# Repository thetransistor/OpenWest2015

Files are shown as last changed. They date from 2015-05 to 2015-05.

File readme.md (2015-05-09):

# OpenWest 2015 Electronic Badge
[OpenWest](https://www.openwest.org/) and [theTransistor](http://thetransistor.com/) bring you another fun conference badge.

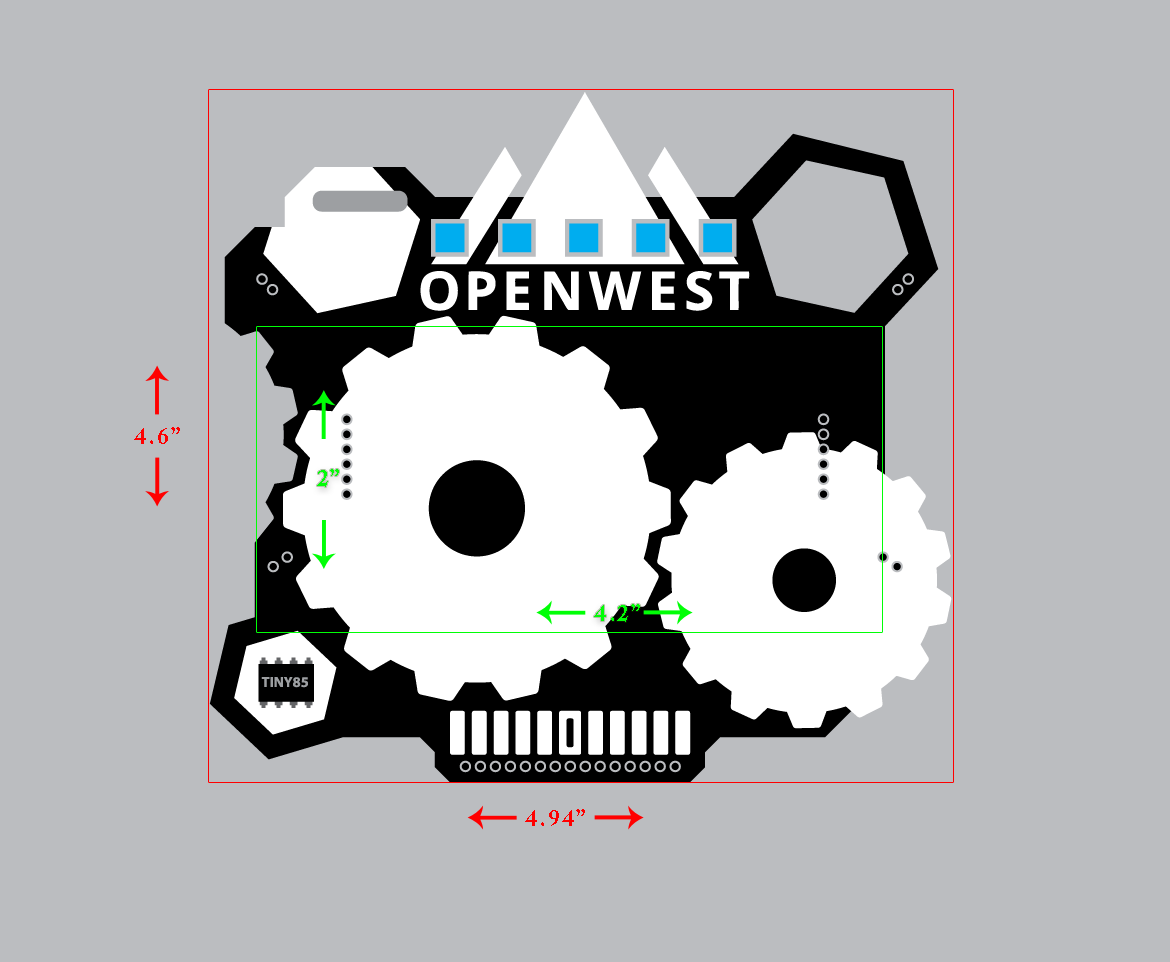
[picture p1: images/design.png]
OpenWest 2015 Badge

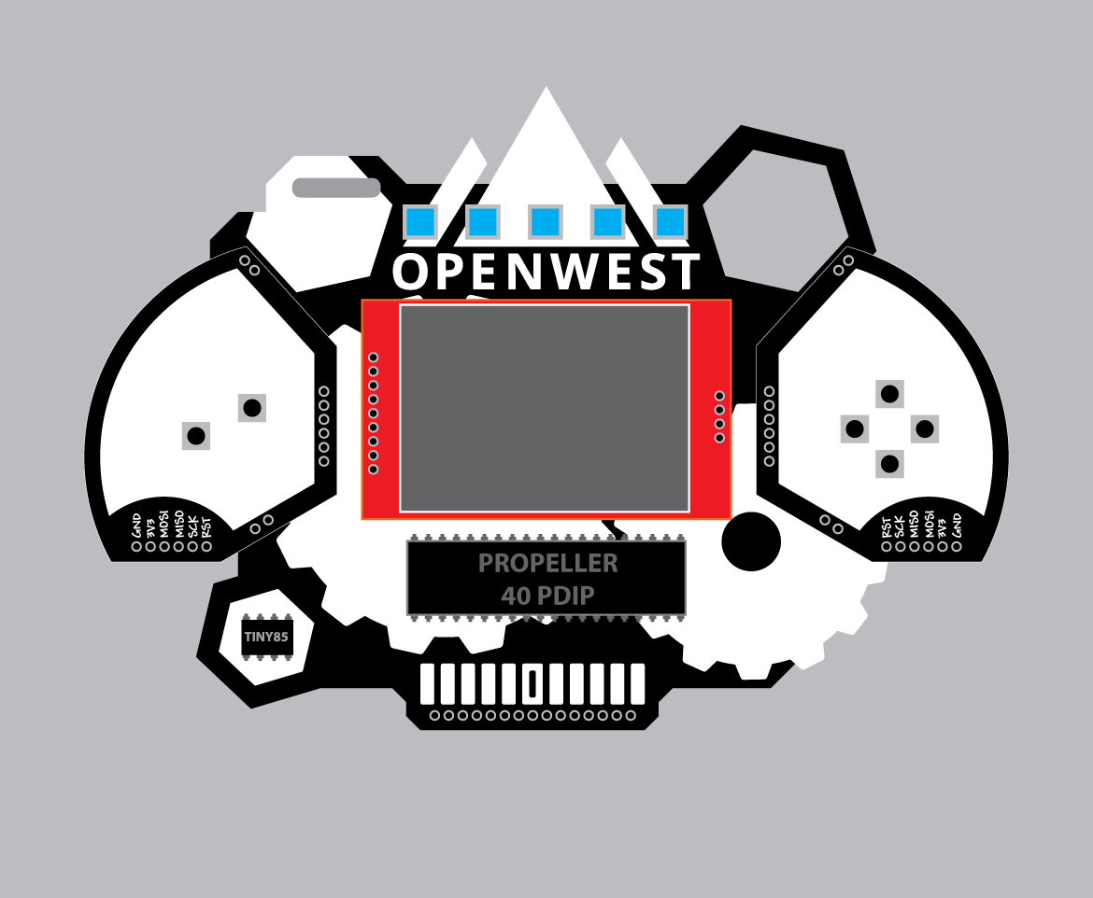
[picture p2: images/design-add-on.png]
OpenWest 2015 Add-On Kit


##Badge Parts List
- 1x Badge PCB
- 1x [ATTiny85](http://www.atmel.com/devices/attiny85.aspx)
- 1x 3xAAA Battery Holder
- 1x Push Button
- 1x Power Switch
- 5x RGB LEDs (WS2812b)
- 6x 0.1uF Capacitors, Ceramic
  
##Badge Add-On Kit Parts List
- 2x Button Board PCBs
- 1x [Parallax Propeller mCU](https://www.parallax.com/product/p8x32a-d40)
- 1x 40 Pin Socket for mCU
- 1x 2.2inch SPI TFT Display
  - [ILI9341 Controller](http://www.adafruit.com/datasheets/ILI9341.pdf)
  - 320x240 Resolution
- 1x 5mhz Crystal Oscillator (mCU runs at 80mhz) 
- 1x 24LC256 EEPROM
- 1x FTD434P MOSFET
- 1x 3.3v LDO Voltage Regulator
- 1x Tilt Switch
- 6x Push Buttons
- 1x Power Switch
- 10x 10k Resistors (labeled 103)
- 2x 10 ohm Resistors (labeled 100)
- 2x 1uF Ceramic Capacitors (with clear backing)
- 2x 0.1uF Ceramic Capacitors (with white backing)
- 1x 40 Pin Header Strip
- 1x SD to microSD Card Adapter
- 1x 128MB microSD Card

##Credits:

**Electronics Work & Processing**
- Compukidmike
- Devino

**Original Design**
- D3c4f

**QA, Assembly, & Loading**
- Animcogn
- Anthony (Demos)
- Trilog
- Nemus
- Evan (Sausage Assassin)
- Damon (Remote) 
- Compukidmike
- Yukaia
- D3c4f
- ProgrammerQ
- aarobc (l3mur)
- Tyrel
- AJ Oneal
- Jay (GraySands)

**Special Thanks**
- MindJuJu
- OpenWest Core Team
- This wonderful community!

##Questions and Comments
Questions and comments can be directed twards the following forms of communication:
- \#dc801 on freenode
- d3c4f [at] thetransistor [dot] com

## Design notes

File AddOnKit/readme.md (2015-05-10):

#How To Hack The Add On#
The add on kit is a [Propeller](http://en.wikipedia.org/wiki/Parallax_Propeller) environment with 6 buttons,
a display, and an SD card. There is an EEPROM bootloader that looks on the SD card and loads the program named run.bin.

##Using the Bitmap Loader##
The bitmap loader program is found under Software/BMP Loader.  It will cycle through two bitmaps it finds
on the SD card.  It will first load default.bmp, then 1.bmp, the back to default.bmp, then 1.bmp, etc, ad nauseum.

To run it, copy all of the contents of Software/BMP Loader to the SD card.

Some notes about creating your own bitmap:
- The badge add on kit is designed to be played while the badge is still around your neck, so when it's hanging the screen is upside down. If you want the bitmaps to be viewed right side up as you walk around, the bitmaps must be flipped both vertically and horizontally.
- The software is pretty picky about the bitmap format. I was successful with exporting the bitmap from GIMP with _**Do not write color space information**_ set and Advanced options set to _**24 bits R8 G8 B8**_

##Using the Button Test##
The button test program shows a letter on the screen for each button.  When a button is pressed the letter corresponding to the button disappears. Use the run.bin file to load the program onto your SD card and run it. Use the spin files to see and modify the source.

##Writing Your Own Code##
- Go get [Propeller IDE](http://developer.parallax.com/projects/propelleride/).
- Write a program in Spin
  - [Intro to Spin programming language](http://letsmakerobots.com/node/18214)
  - [Propeller Spin Tutorials](http://learn.parallax.com/propeller-spin-tutorials)
  - [Helpful Propeller Instructable](http://www.instructables.com/id/Programming-the-Propeller-Microcontroller/)
  - [Badge Spin Example](https://github.com/thetransistor/OpenWest2015/tree/master/AddOnKit/Software)
- Build the program in the IDE
- Rename the binary to run.bin
- Put the binary on the SD card
- Profit!!!

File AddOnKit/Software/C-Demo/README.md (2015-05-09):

C++ Demo
=============
This is a basic demo of using C++ on the OpenWest 2015 conference badge. The LCD driver was converted using spin2cpp. 

##Writing Your Own Code##
- Go get [SimpleIDE](http://learn.parallax.com/propeller-c-set-simpleide).
- Write a program in C++ or convert a library from spin
  - [Propeller GCC Tutorials](https://sites.google.com/site/propellergcc/documentation/tutorials)
  - [spin2cpp Tutorials](https://sites.google.com/site/propellergcc/documentation/tutorials/spin2cpp)
- Build the program in the IDE
- Rename the binary to run.bin
- Put the binary on the SD card
- Profit!!!

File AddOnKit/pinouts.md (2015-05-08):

# OpenWest 2015 Electronic Badge Pinout
Pinouts for the add on kit.

LCD Pin | Propeller IO
--------|--------------
CS | P7
RST | P8
D/C | P9
MOSI | P10
SC | P11
MISO | P21

Misc | Propeller IO
---|---
Backlight | P6
TILT Sensor | P16

SD Card | Propeller IO
---|---
CS | P5
MOSI | P4
MISO | P3
SCK | P21

EEPROM | Propeller IO
---|---
SCL | P28
SDA | P29

Button | Propeller IO
---|---
Up | P0
Down | P1
Left | P27
Right | P26
A | P13
B | P14

## Serial EEPROM Programming / Spin Connection
NOTE: Verify your FTDI is using 3.3v AND 3.3v logic levels!

FTDI Serial | Badge
---|---
RTS | RST
TX | RX
RX | TX
GND | GND

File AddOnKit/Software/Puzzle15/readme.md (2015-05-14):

#15 Sliding Puzzle 15 Game
Designed for the upgraded badge from the OpenWest 2015 Conference

[Author: Michael Peters](https://github.com/bluehawk)

"Totally open license, you may use this code however you wish, but I'm not responsible for your actions."

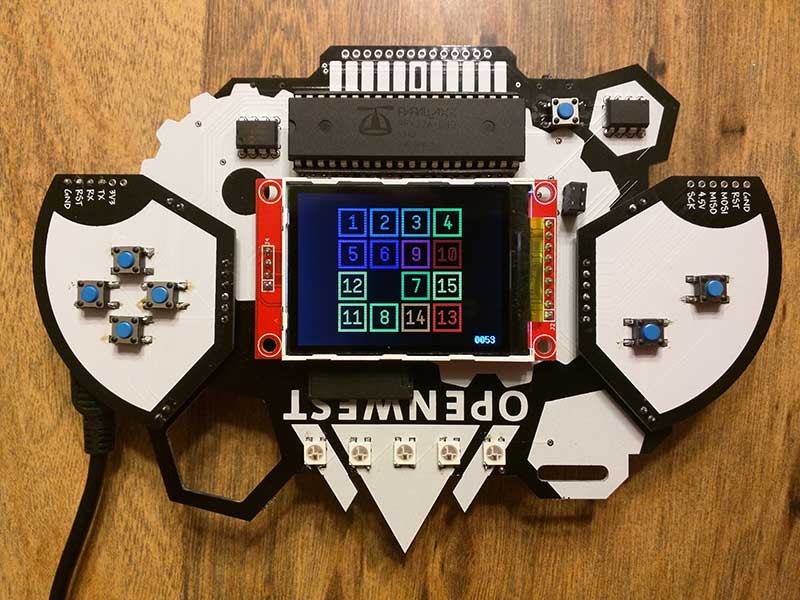
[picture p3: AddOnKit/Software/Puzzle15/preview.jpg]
Step One Image


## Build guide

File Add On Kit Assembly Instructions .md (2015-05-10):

# OpenWest 2015 Electronic Badge Add-On Kit
Assembly Instructions
(Adapted from original instructions created by Compukidmike)

## Step 1: Identify Parts
Step 1: Identify Parts
You should have the following parts in your kit:
- 2x Button Boards
- 1x [2.2" Color LCD](http://www.adafruit.com/datasheets/ILI9341.pdf)
- 1x [Propeller Microcontroller](https://www.parallax.com/product/p8x32a-d40)
- 1x 40 Pin Socket
- 6x Tactile Buttons
- 1x Slide Switch
- 1x Tilt Switch
- 2x 0.1uF Capacitors (in the white packaging)
- 2x 1uF Capacitors (in the clear packaging)
- 10x 10K Ohm Resistors
- 2x 10 Ohm Resistors
- 1x Voltage Regulator
- 1x Mosfet
- 1x 5 MHZ Crystal
- 1x EEPROM
- 1x Micro SD Card
- 1x SD Card Adapter
- 1x Pin Strip

If you are missing parts, please let us know. 
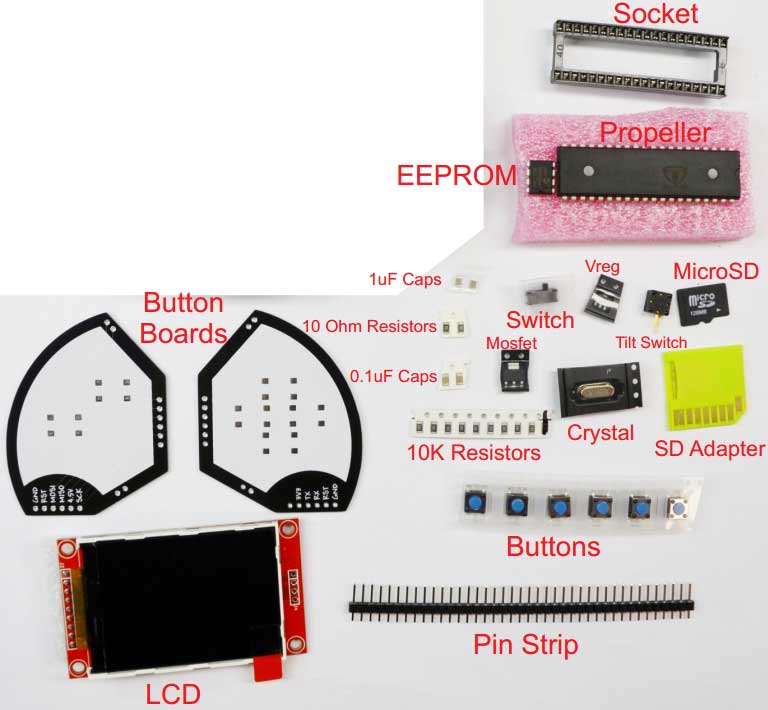
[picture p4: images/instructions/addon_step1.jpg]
Step One Image


NOTE: The surface mount parts come in a plastic or paper tray with a thin plastic film
over them. You will need to peel this plastic off to get the parts out. BE CAREFUL
when doing this as these small parts tend to go flying everywhere.

NOTE: The easiest way to solder surface mount parts is to first put solder on one of
the pads on the board. Then, while holding the soldering iron on that pad to keep the
solder melted, use the tweezers to place the part onto the board. You can then solder
the other side of the part.

## Step 2: Voltage Regulator
- Flip the board over to the back. 
- Locate the marking for VR1. This is where the Voltage Regulator goes. Be sure that the three pins on the bottom are not shorted together after soldering. This is by far the hardest part to solder on the board.

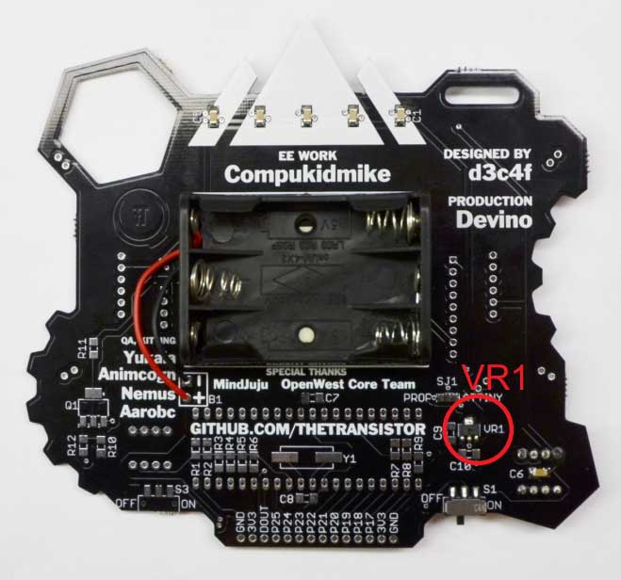
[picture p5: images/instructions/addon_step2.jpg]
Step Two Image


## Step 3: Capacitors
- There are TWO DIFFERENT types of capacitors in this kit, but they look identical. Only open one type at a time.
- The capacitors and resistors are easy to confuse because they are the same size. The resistors are black with white numbers, while the capacitors are brown and unmarked.
- First, locate the two 1uF capacitors. They are in a CLEAR plastic strip. Place them on C9 and C10 (next to the voltage regulator from the previous step).
- Next, locate the two 0.1uF capacitors. They are in a WHITE paper strip. Place them on C7 and C8 (middle of the board).

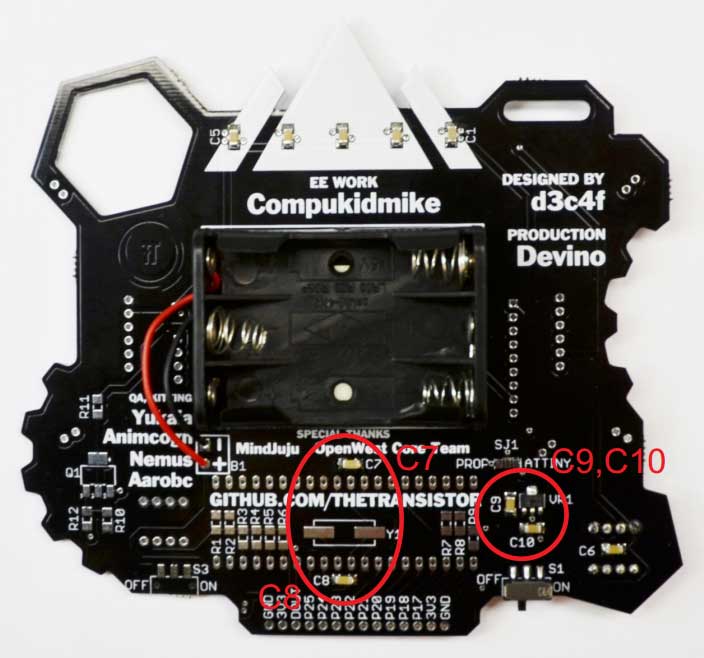
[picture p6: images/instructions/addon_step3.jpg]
Step Three Image


## Step 4: Resistors
- There are TWO DIFFERENT values of resistors.
- The strip of 10 resistors are 10K Ohms (Labeled 103 on the resistors).
- The strip of 2 resistors are 10 Ohms. (Labeled 100 on the resistors)
- Place the ten 10K resistors on R1-R10.
- Place the two 10 Ohm resistors on R11-R12.

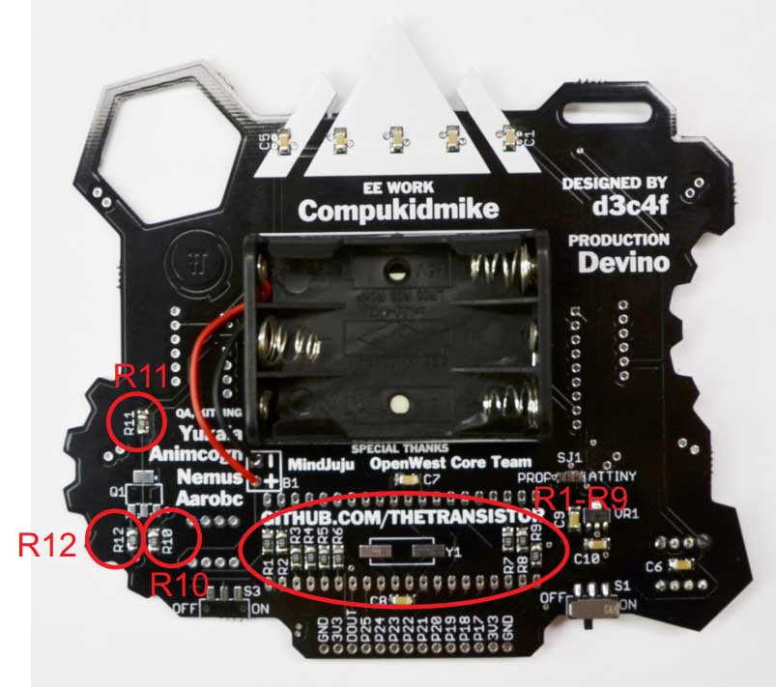
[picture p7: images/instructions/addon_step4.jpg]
Step Four Image


## Step 5: Mosfet, Crystal and Switch
- Locate Q1 and place the mosfet there.
- The Crystal goes on Y1.
- Then solder the slide switch on S3.

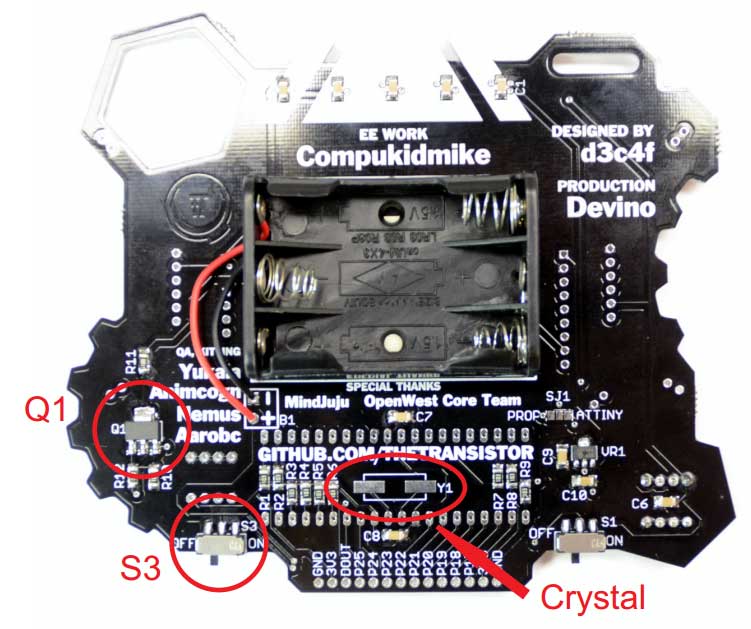
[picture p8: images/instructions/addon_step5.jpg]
Step Five Image


## Step 6: Tilt Switch, EEPROM and Socket
- Place the tilt switch on the front of the board. There are four small marks that show the outline of the switch. Make sure it lines up with the marks, and then solder the switch.
- Next, place the EEPROM. The orientation on this chip is opposite from the ATTiny85 microcontroller from the base kit. The pin 1 marking goes on the top right corner. This chip also has a half-circle shaped dimple on one side of the chip. This should face towards the right side of the board.
- Then place the 40 pin socket on the front of the board. There is a dimple on one side of the socket. Align this with the mark on the board (it should face towards the right side of the board).

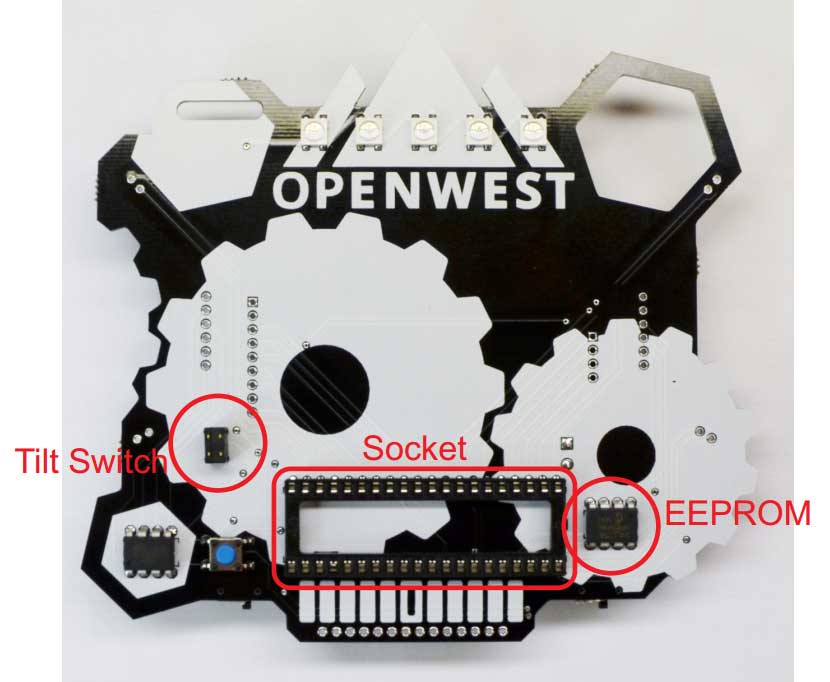
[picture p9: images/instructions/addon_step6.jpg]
Step Six Image


## Step 7: LCD
- The LCD is tricky. The first thing to note is that the display only has pins on one side. You will need to cut 4 of the pins from the pin strip to put on the display. DON’T solder them to the display yet!
- While holding the pins in place on the display, put the display in place on the front of the board.
- Carefully flip the board over and solder the first pin on the right side of the board (the pad on the board is square shaped).
- Now you need to check that the display is parallel to the front of the board. It tends to not lay flat due to the SD card socket on the back. One way to fix it is to gently squeeze the board and display where the SD card is located, while at the same time re-heating the solder joint on the first pin. When the solder melts, the screen will ‘snap’ into the correct position.
- You can then solder the rest of the pins.

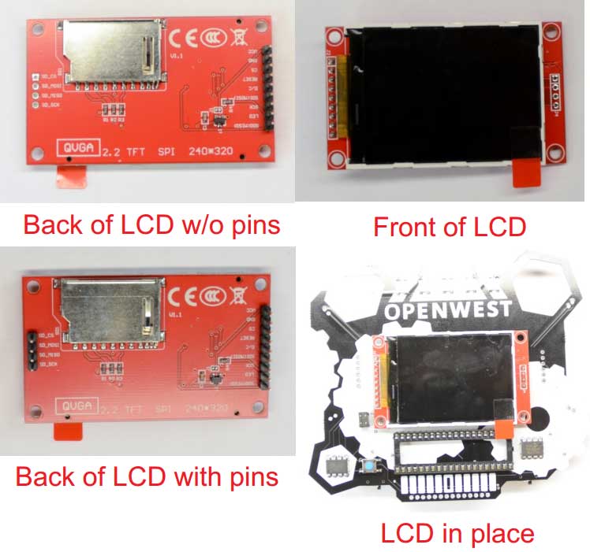
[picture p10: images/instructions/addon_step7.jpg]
Step Seven Image


##Step 8: Button Boards
- The button boards are interesting. They are both identical, but each side is
different. We will use one of each side to produce the required button layout.
- Start by soldering the Left and Right buttons on the Right board.
- Then do the top and bottom buttons
- And finally solder the two buttons on the left board.

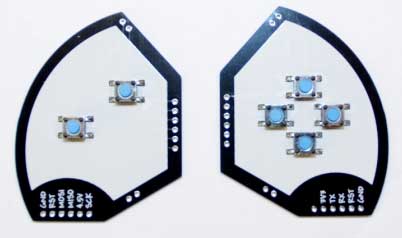
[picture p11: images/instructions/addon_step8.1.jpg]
Step Eight One Image


- Once the boards are done, you will need to cut more pins from the pin strip.
- Cut four sets of 2 pins and two sets of 6 pins.
- Place them in the main board with the long side down.
- Now place the button boards on top of the pins. They will not stay by themselves. While holding both boards, flip them over. Now gravity will help the button boards stay flat while you solder all the pins.
- Next, flip the board back over and solder the top of the pins on the button
boards.

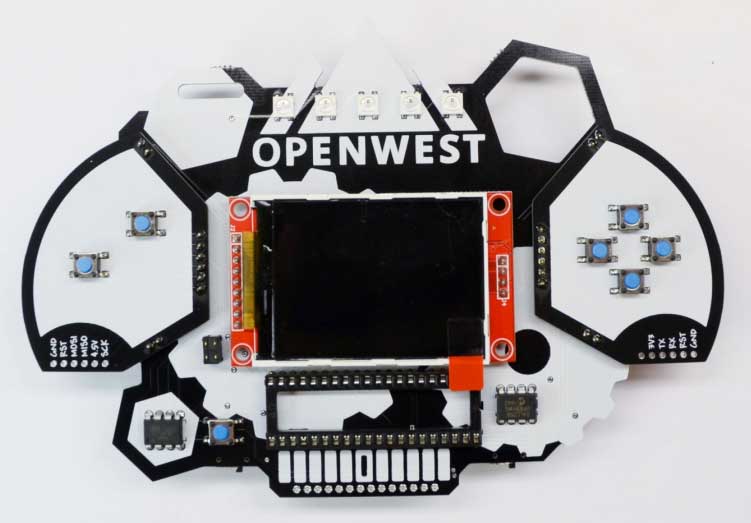
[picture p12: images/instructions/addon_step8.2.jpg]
Step Eight Two Image


## Step 9: Propeller and SD Card
- The end is near! It’s now time to put in the propeller chip. This is a big chip, and it’s expensive so please be careful with it.
- To get the chip into the socket, you will need to bend the legs inward slightly. The easiest way to do this is to put the chip on its side on a flat surface. Then GENTLY press the chip down so that all the pins on that side bend inward a little. Flip the chip over and repeat on the other side.
- Now the pins should be pointing straight down on the sides of the chip.
- Make sure that the dimple is on the right side of the chip and place it into the socket. It will take some force to press it in, so be sure that it is lined up properly.
- After the propeller is in place, put the MicroSD card into the SD adapter and place it in the top of the LCD.

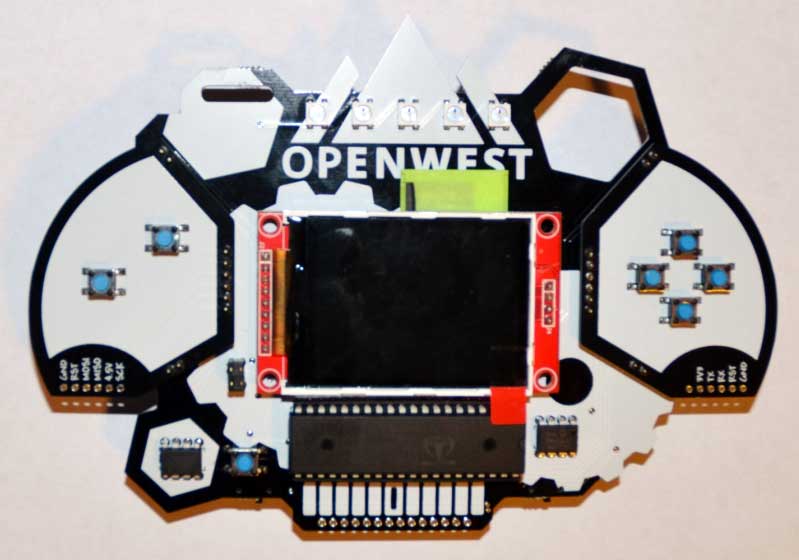
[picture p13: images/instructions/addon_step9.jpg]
Step Nine Image


## Step 9: Test
- You’re done! Put some batteries in, flip the new switch to “ON” and the LCD should light up and display some test patterns. 
- If it doesn’t, please let us know and we’d be happy to help you get it working.
- Enjoy your add-on kit!

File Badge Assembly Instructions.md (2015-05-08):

# OpenWest 2015 Electronic Badge
Assembly Instructions
(Adapted from original instructions created by Compukidmike)

## Step 1: Identify Parts
- 1x Badge PCB
- 1x [ATTiny85](http://www.atmel.com/devices/attiny85.aspx)
- 1x 3xAAA Battery Holder
- 1x Push Button
- 1x Power Switch
- 5x RGB LEDs (WS2812b)
- 6x 0.1uF Capacitors, Ceramic
- 1x Double-Sided Sticky Square

If you are missing parts, please let us know. 
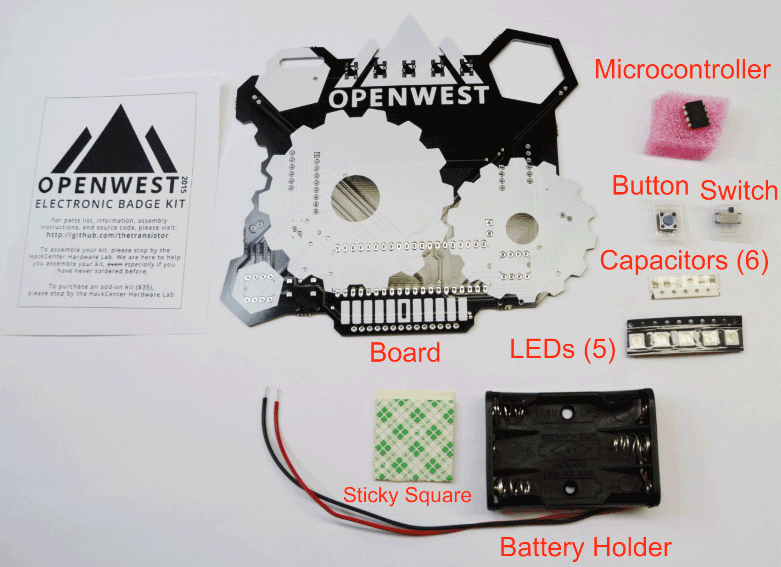
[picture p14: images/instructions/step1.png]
Step One Image


## Step 2: Capacitors and Switch
- Flip the board over to the back. Locate the markings for C1-C5 and C6.
- Solder the 6 capacitors. Orientation does not matter for the capacitors.
- Locate S1 and solder the switch there. The switch has little plastic tabs on the bottom that fit into holes on the board.
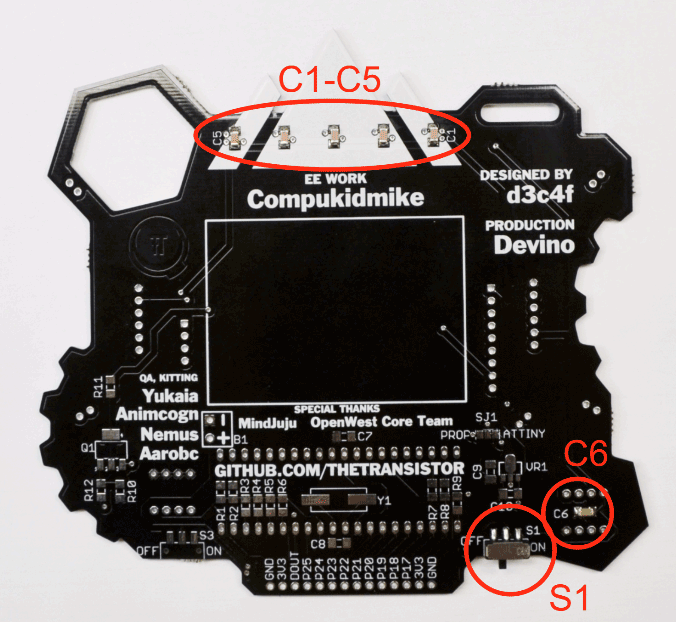
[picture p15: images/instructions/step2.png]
Step Two Image


Note: The surface mount parts come in a plastic or paper tray with a thin plastic film
over them. You will need to peel this plastic off to get the parts out. BE CAREFUL
when doing this as these small parts tend to go flying everywhere.

Note: The easiest way to solder surface mount parts is to first put solder on one of
the pads on the board. Then, while holding the soldering iron on that pad to keep the
solder melted, use the tweezers to place the part onto the board. You can then solder
the other side of the part.

## Step 3: LEDs and Button
- Flip the board back over to the front. Locate the 5 sets of pads at the top of the board, above the OPENWEST text. This is where the LEDs go.
- Orientation is critical for these parts! There are two ways to make sure you put them on the correct way. The easiest is to find the small brown rectangle inside the LED. This should be towards the top of the board. The other way is to find the cut off corner on the LED. This should correspond to a triangle on the board.
- Once you have determined the correct orientation for the LEDs, solder all 5 of them.
- Then, locate the button in the bottom left corner of the board and solder it.
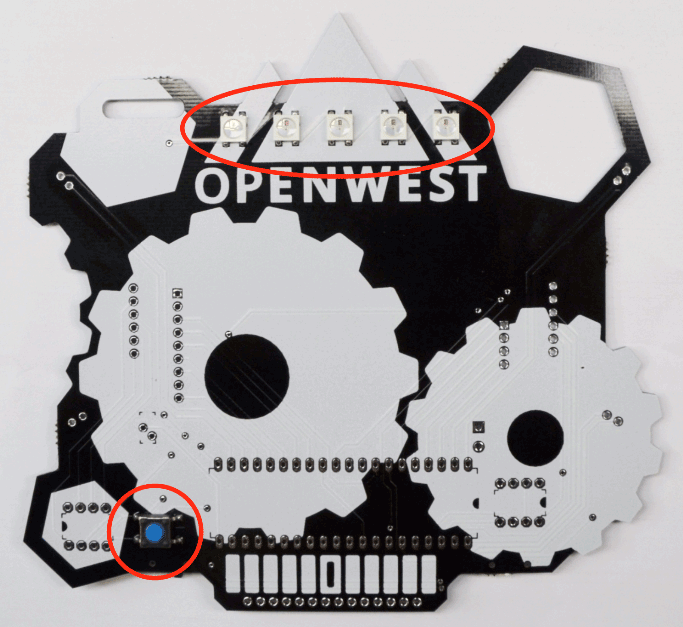
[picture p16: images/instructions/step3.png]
Step Three Image

Note: Solder the LEDs and button the same way as the capacitors. Put
solder on one pad, place the part, and then solder the rest of the pads.

## Step 4: Microcontroller
It’s time for the Microcontroller. The Badge uses an Atmel ATTiny85. Once again, orientation matters! The microcontroller goes in the bottom left corner of the board. There is a marking on the top next to pin 1. This marking should be in the bottom-left corner of the chip (pointing to the left). If you are unsure of the correct orientation, please ask us before soldering it!
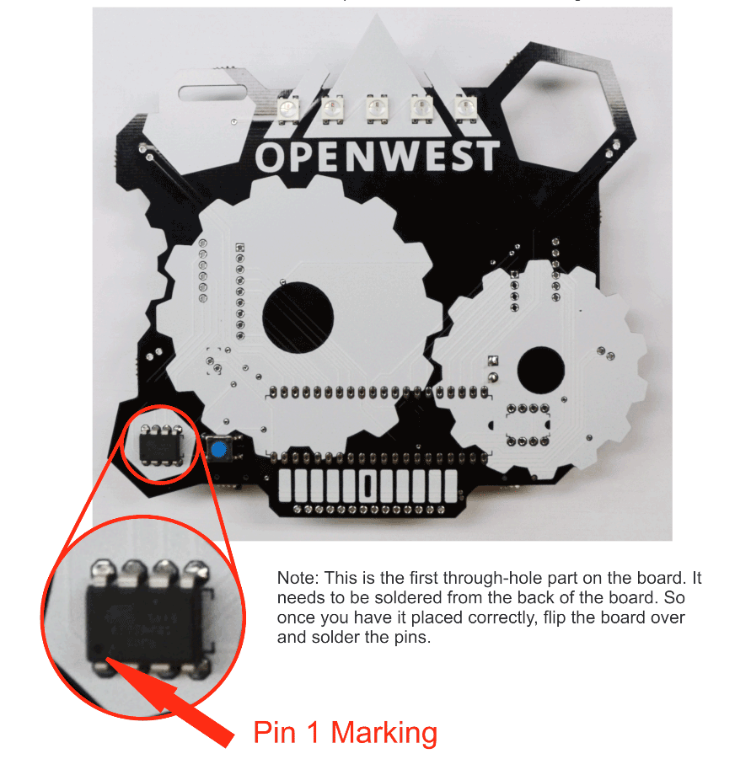
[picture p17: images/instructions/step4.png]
Step Four Image


## Step 5: Battery Holder
This is it, the final piece! 
- The first thing to do is put the sticky square on the bottom of the battery holder. You might need to adjust the wire on the bottom so that it fits in the groove.
- Then place the battery holder on the board with the wires coming out to the left.
- Now you will need to cut the wires to the correct length. They need to reach the square marked B1. The black wire goes to the “-” and the red wire goes to the “+”.
- Once you cut the wires, strip off about 1/4” of insulation.
- Place the wires through the holes and solder them on the front side of the board, then cut off the excess wire close to the board.

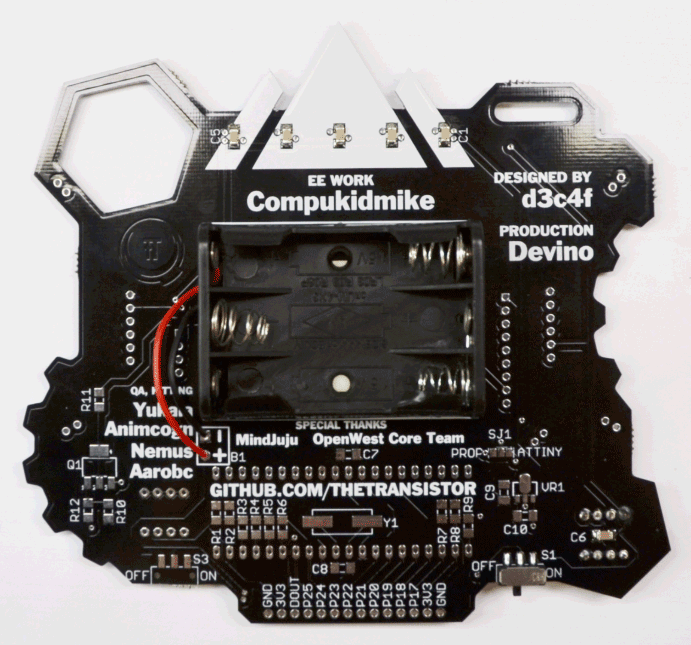
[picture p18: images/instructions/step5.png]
Step Five Image


## Step 6: Test
- Install a set of batteries (available up front)
- Slide your power switch to "ON" 
- Check that all 5 LEDs light up
- If you have any trouble, please switch off the device and bring it to one of the staff members to help you diagnose.

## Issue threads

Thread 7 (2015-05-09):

USB debugging/loading?

therebelrobot, 2015-05-09:
So I'm finding that I need to pull out the sd card and reload it every time I want to test something new on the board, which can get tedious after enough updates. Is the board expandable enough to include a usb extension? I would love to just plug this in and test out stuff without leaving my keyboard.

therebelrobot, 2015-05-09:
@d3c4f, are you the one to ask about this? I forget if it was you or someone else that built the board...

bluehawk, 2015-05-09:
From what I can tell, you could buy this (rather expensive) $15 [USB plug](https://www.parallax.com/product/32201) and connect it to the right wing of the badge to the TX, RX, RST, GND pins.

But at $15 just for a usb plug, I might just pay a bit more and get a propeller board with more expansion capability to play with.

* The $25 [USB project board](https://www.parallax.com/product/32810) has usb and lots of places to solder (permanent) connections.
* The $35 [quickstart board](https://www.parallax.com/product/40000) has a usb port, plus 8 leds and buttons on the board ready to use, plus headers that you can use to test things and reuse.
* You can get even more expensive $50 or $120 boards that include breadboards if you want to have ultimate reusability, plus things like VGA, audio, microsd, etc.

At the same time, I do like the form factor of the badge. It's a tough choice.

d3c4f, 2015-05-10:
Any 3.3v FTDI (or knockoff) programmer is capable of programming the badge. They are very handy to have separately, not just for this project but also for many other mCU work. If $15 is a bit pricey (you're just going to be playing with this from time to time), I would look into a knockoff USB -> Serial FTDI-Style device. You can get these for as little as $3 (shipped) on aliexpress.

d3c4f, 2015-05-10:
To close this out:
- You absolutely can test code over the serial connection (for USB, use an FTDI $3 for a knock off, or $15 for "the real deal") without booting to the EEPROM->SD card each from.
- With the Propeller IDE you can load code directly into RAM instead of writing to persistent storage (EEPROM / SD Card), which is SUPER handy for testing code.
- I designed the board (Picked out the major components, came up with the concept, did the artwork / outlines / etc). Compukidmike took that and did all the PCB and EE work (routing traces, checking datasheets / etc).

therebelrobot, 2015-05-11:
@bluehawk & @d3c4f, thanks a million! I'll look up getting an FTDI, and see how that goes. Super awesome concept and execution, I might add, thanks so much for an awesome OpenWest badge!

Closed 2015-05-10.

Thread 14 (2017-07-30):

2015 Add-on kit troubleshooting

dstockto, 2017-07-30:
Hey, I know this is a long shot since it has been two years, but I just got the equipment and time together today and assembled and attached the addon for my 2015 OpenWest badge. And it worked, first time. Then I loaded the BMP viewer and it worked. So then I made some images to show and they didn't work and then I found I had exported them as 32 bit instead of 24, so I fixed that and that worked. And then I turned it off and back on again and it worked. Then I turned it off and back on again and showed my wife and it worked. And then I went to show my kids and after turning it off, it wouldn't turn on again.

The original circuit with the blinkenlights is still working, it's just the add-on one. I'm pretty new to all this stuff so if you're able and willing to, if you could point me to some things to try or look at to figure out what's going on, I'd appreciate it. If not, no worries.

Thank you in advance.

d3c4f, 2017-08-02:
David,

Thanks for the questions, and sorry for the delay in answering them. I have
been at conferences for the past 2-3 weeks.

There are a couple things to check:
1) The SD data is corrupted. Try reformatting it and loading the code onto
it again.
2) The SD card is not corrupted. Try a new SD card.
3) The bootloader could be corrupted (I can't remember if it is built into
the chip or not). If it is, you will need to load a new one via the serial
programming headers for the propeller (you will likely need an FTDI
USB->Serial adapter). See link below and expand the downloads section.
4) The Propeller chip has somehow been damaged. You will need to replace
it. (see link below)

Propeller Chip:
https://www.parallax.com/product/p8x32a-d40

3.3v FTDI Programmer:
https://www.sparkfun.com/products/9873

3.3v FTDI Programmer (cheap Chinese knockoff, verify voltage!):
https://www.aliexpress.com/item/Free-shipping-1pcs-FT232RL-FTDI-USB-3-3V-5-5V-to-TTL-Serial-Adapter-Module-for/32294938771.html

I hope that helps,
d3c4f

On Sat, Jul 29, 2017 at 9:45 PM, David Stockton <notifications@github.com>
wrote:

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

dstockto, 2017-08-03:
No worries on the delay. Thank you for the reply.

I don't *think* the SD card is corrupted as I'm able to copy new things to it without error, but I'll give that a shot, or try another. I would suspect I may be dealing with suggestion 3, but I'll try the first 2 first. Hopefully, the chip isn't damaged.

Thank you for the suggestions. I'll reply back after I've tried some stuff or succeeded.

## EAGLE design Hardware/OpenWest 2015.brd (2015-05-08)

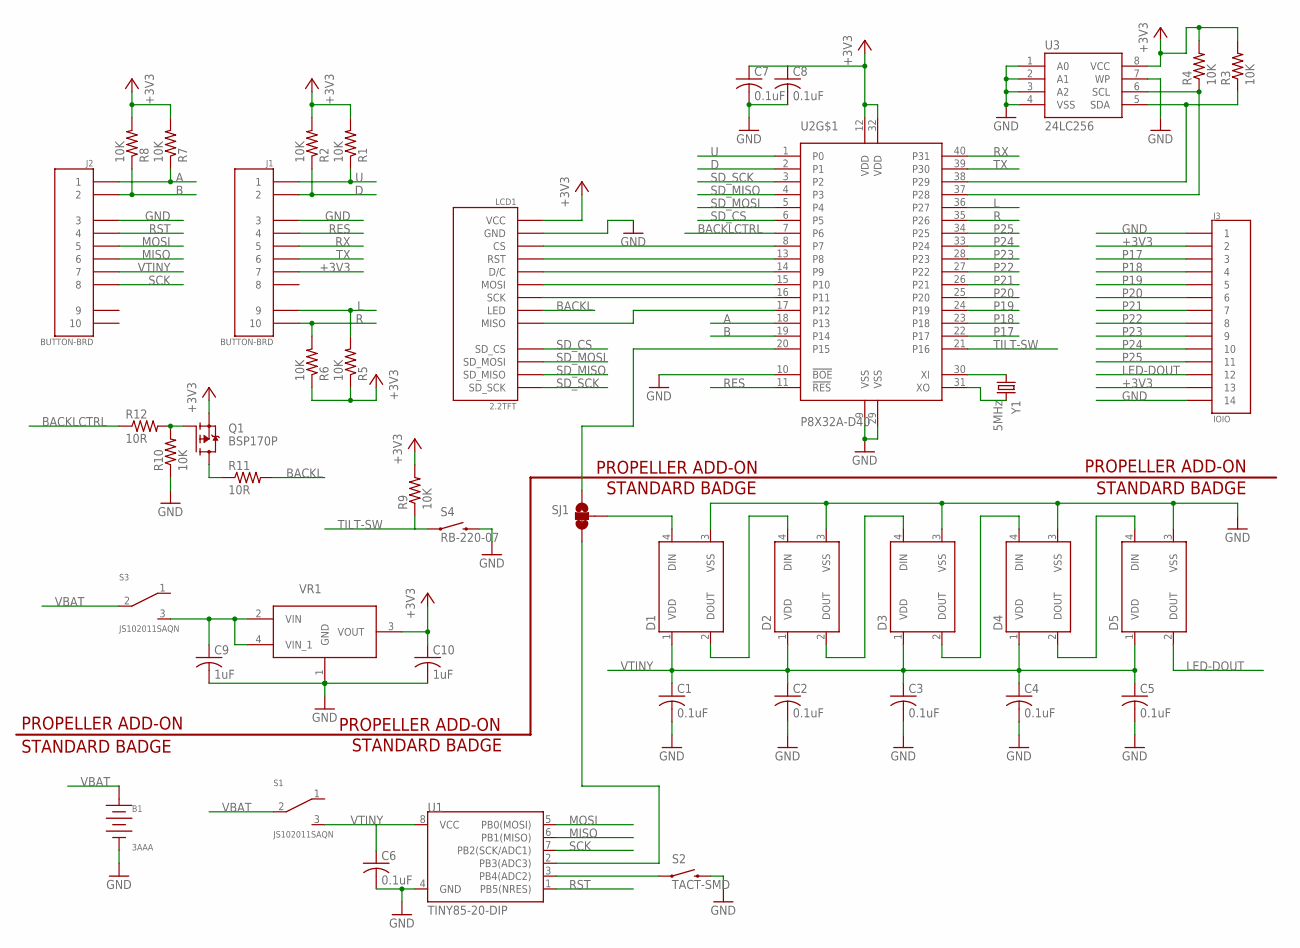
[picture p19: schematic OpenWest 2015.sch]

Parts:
B1: 3AAA; FLYING-LEADS
C1, C2, C3, C4, C5, C6, C7, C8: 0.1uF; C1206K
C9, C10: 1uF; C1206K
D1, D2, D3, D4, D5: WS2812B
J1, J2: BUTTON-BRD
J3: IOIO
LCD1: 2.2TFT
Q1: BSP170P; SOT223
R1, R2, R3, R4, R5, R6, R7, R8, R9, R10: 10K; R1206
R11, R12: 10R; R1206
S1, S3: JS102011SAQN; SAQN
S2: TACT-SMD
S4: RB-220-07; SPST
SJ1: JUMPER-PAD-3-2OF3_NC_BY_TRACE_LARGE; PAD-JUMPER-3-2OF3_NC_BY_TRACE_YES_SILK_LARGE
U1: TINY85-20-DIP; DIP08
U2: P8X32A-D40; DIP-40
U3: 24LC256; DIP08
VR1: MCP17-MCP1700T-3302E/MB; SOT150P400X160-4N
Y1: 5MHz; CRYSTAL-SMD

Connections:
+3V3: C7.1, C8.1, C10.1, J1.7, J3.P$2 (2), J3.P$13 (13), LCD1.VCC, Q1.3 (S), R1.2, R2.2, R3.2, R4.2, R5.1, R6.1, R7.2, R8.2, R9.2, U2.12 (VDD), U2.32 (VDD), U3.8 (VCC), VR1.3 (VOUT)
A: J2.1, R7.1, U2.18 (P13)
B: J2.2, R8.1, U2.19 (P14)
BACKL: LCD1.LED, R11.2
BACKLCTRL: R12.1, U2.7 (P6)
D: J1.2, R2.1, U2.2 (P1)
GND: B1.-, C1.2, C2.2, C3.2, C4.2, C5.2, C6.2, C7.2, C8.2, C9.2, C10.2, D1.3 (VSS), D2.3 (VSS), D3.3 (VSS), D4.3 (VSS), D5.3 (VSS), J1.3, J2.3, J3.P$1 (1), J3.P$14 (14), LCD1.GND, R10.1, S2.P$3 (2), S4.2, U1.4 (GND), U2.9 (VSS), U2.10 (!BOE), U2.29 (VSS), U3.1 (A0), U3.2 (A1), U3.3 (A2), U3.4 (VSS), U3.7 (WP), VR1.1 (GND)
L: J1.9, R5.2, U2.36 (P27)
LED-DOUT: D5.2 (DOUT), J3.P$12 (12)
MISO: J2.6, U1.6 (PB1(MISO))
MOSI: J2.5, U1.5 (PB0(MOSI))
unnamed: D1.4 (DIN), SJ1.2
unnamed: D1.2 (DOUT), D2.4 (DIN)
unnamed: D2.2 (DOUT), D3.4 (DIN)
unnamed: D3.2 (DOUT), D4.4 (DIN)
unnamed: D4.2 (DOUT), D5.4 (DIN)
unnamed: R4.1, U2.37 (P28), U3.6 (SCL)
unnamed: R3.1, U2.38 (P29), U3.5 (SDA)
unnamed: SJ1.3, U1.2 (PB3(ADC3))
unnamed: SJ1.1, U2.20 (P15)
unnamed: LCD1.CS, U2.8 (P7)
unnamed: LCD1.RST, U2.13 (P8)
unnamed: LCD1.D/C, U2.14 (P9)
unnamed: LCD1.MOSI, U2.15 (P10)
unnamed: LCD1.SCK, U2.16 (P11)
unnamed: LCD1.MISO, U2.17 (P12)
unnamed: U2.30 (XI), Y1.P$1 (1)
unnamed: U2.31 (XO), Y1.P$2 (2)
unnamed: C9.1, S3.3, VR1.2 (VIN), VR1.4 (VIN_1)
unnamed: S2.P$1 (1), U1.3 (PB4(ADC2))
unnamed: Q1.2 (D), Q1.4 (D), R11.1
unnamed: Q1.1 (G), R10.2, R12.2
P17: J3.P$3 (3), U2.22 (P17)
P18: J3.P$4 (4), U2.23 (P18)
P19: J3.P$5 (5), U2.24 (P19)
P20: J3.P$6 (6), U2.25 (P20)
P21: J3.P$7 (7), U2.26 (P21)
P22: J3.P$8 (8), U2.27 (P22)
P23: J3.P$9 (9), U2.28 (P23)
P24: J3.P$10 (10), U2.33 (P24)
P25: J3.P$11 (11), U2.34 (P25)
R: J1.10, R6.2, U2.35 (P26)
RES: J1.4, U2.11 (!RES)
RST: J2.4, U1.1 (PB5(NRES))
RX: J1.5, U2.40 (P31)
SCK: J2.8, U1.7 (PB2(SCK/ADC1))
SD_CS: LCD1.SD_CS, U2.6 (P5)
SD_MISO: LCD1.SD_MISO, U2.4 (P3)
SD_MOSI: LCD1.SD_MOSI, U2.5 (P4)
SD_SCK: LCD1.SD_SCK, U2.3 (P2)
TILT-SW: R9.1, S4.1, U2.21 (P16)
TX: J1.6, U2.39 (P30)
U: J1.1, R1.1, U2.1 (P0)
VBAT: B1.+, S1.2, S3.2
VTINY: C1.1, C2.1, C3.1, C4.1, C5.1, C6.1, D1.1 (VDD), D2.1 (VDD), D3.1 (VDD), D4.1 (VDD), D5.1 (VDD), J2.7, S1.3, U1.8 (VCC)

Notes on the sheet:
STANDARD BADGE
PROPELLER ADD-ON

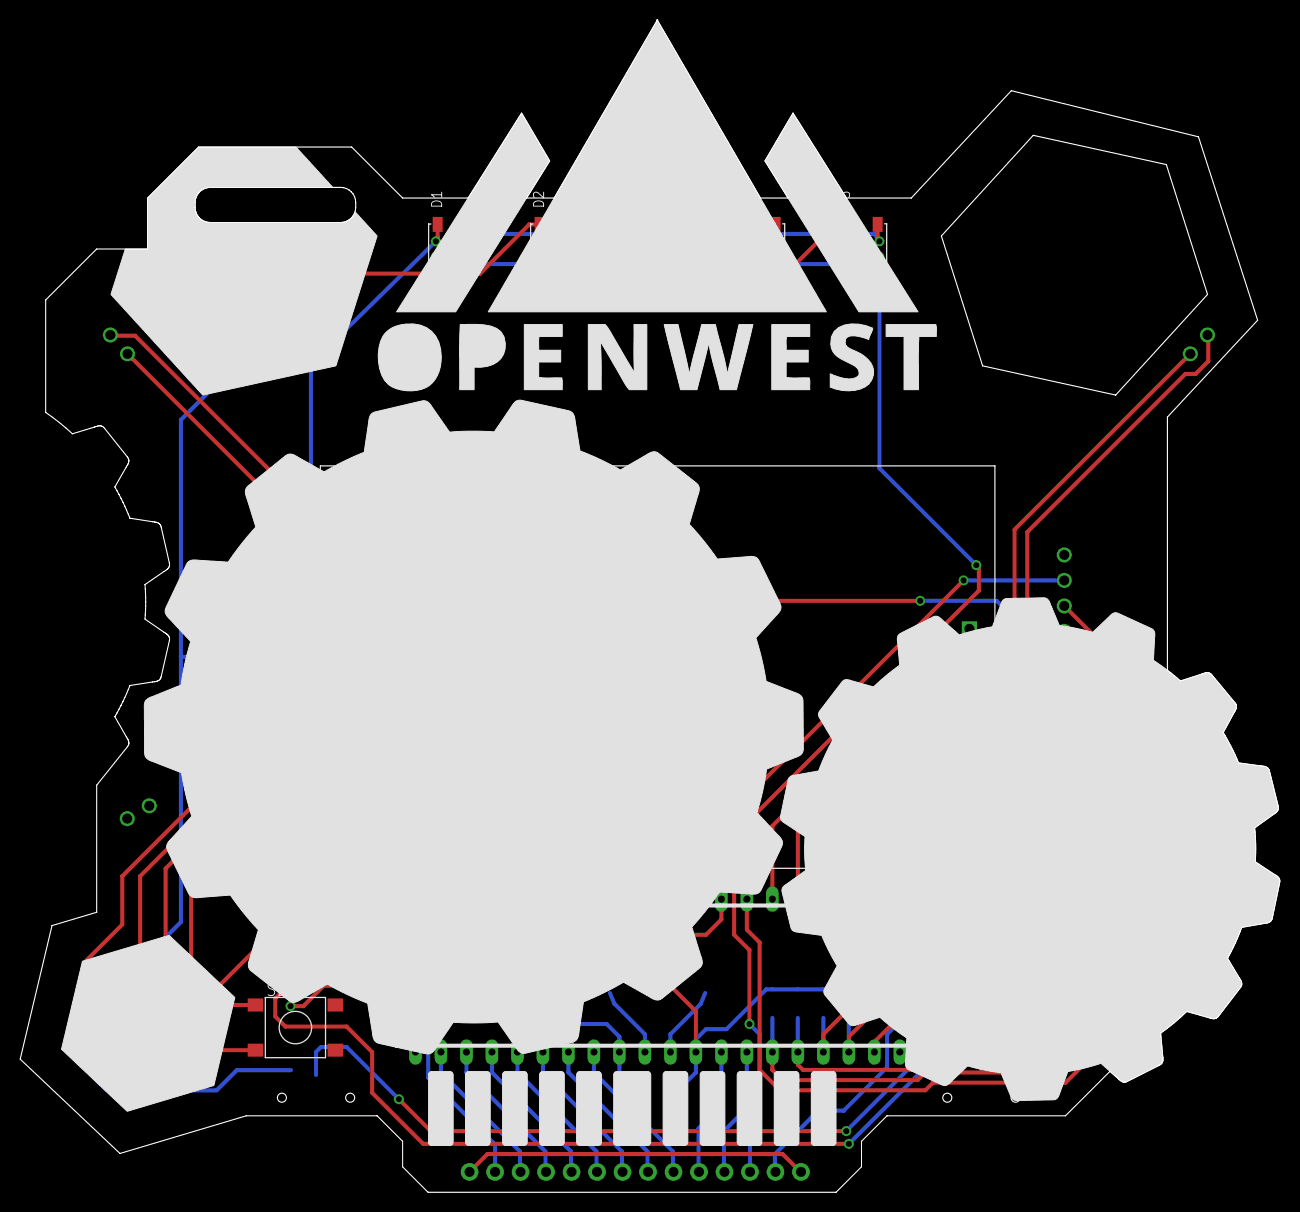
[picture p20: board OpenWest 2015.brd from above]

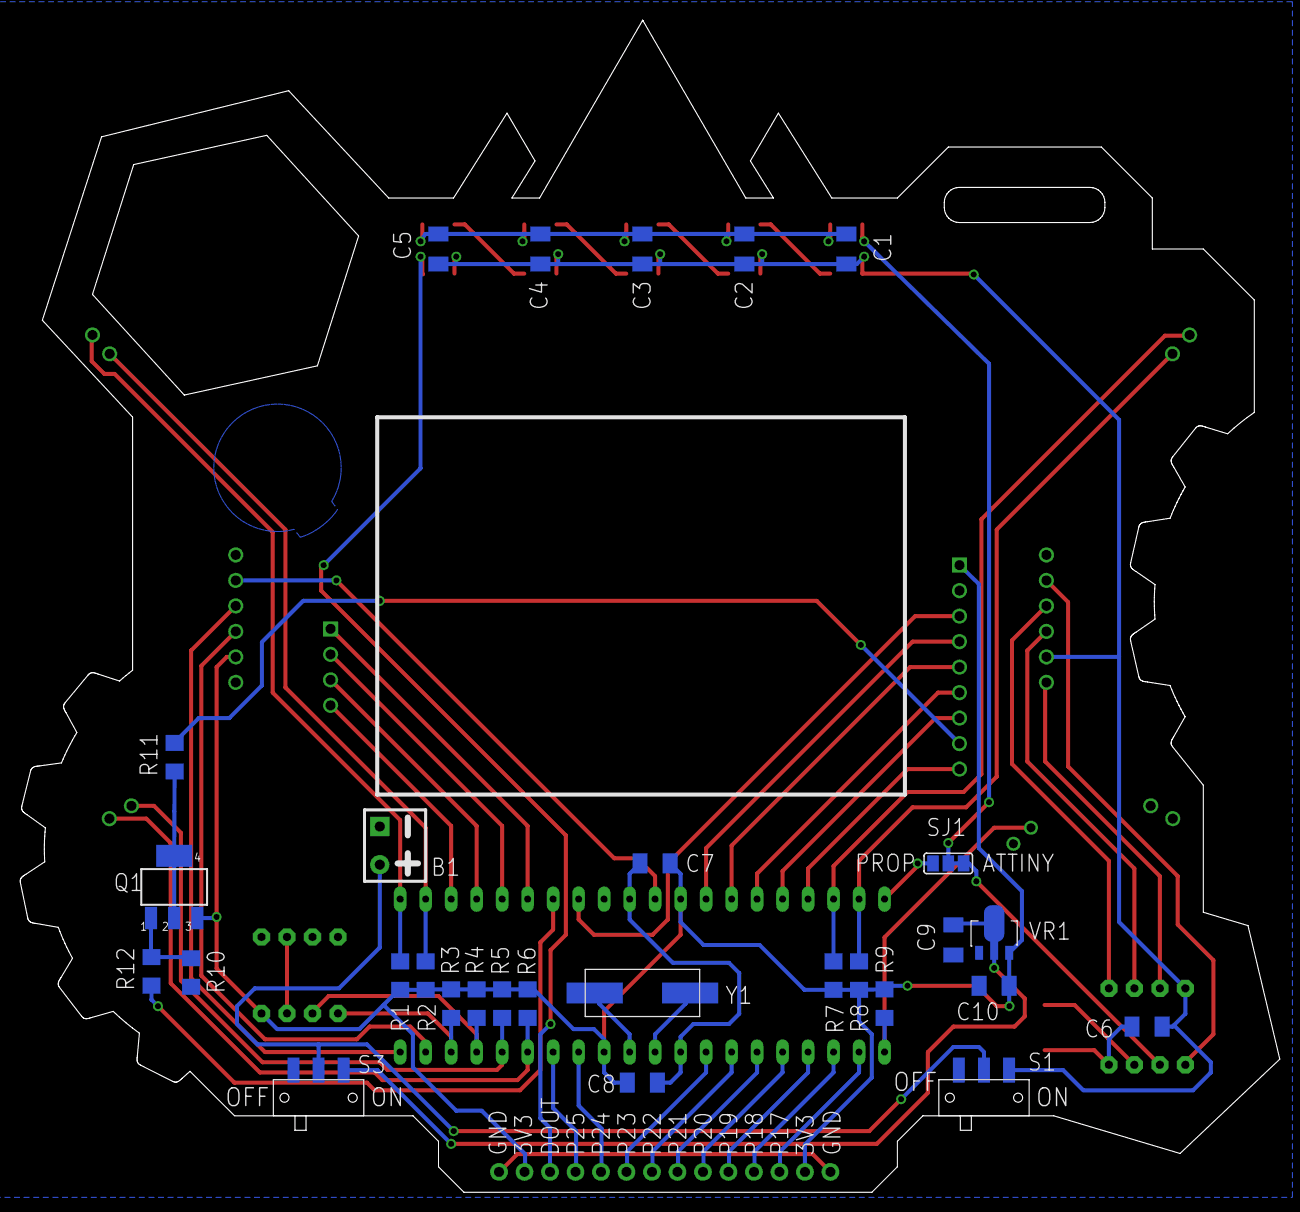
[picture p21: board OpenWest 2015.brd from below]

Board: 5 copper layers, 125.5 x 116.8 mm, 43 parts (30 on the bottom side), 55 nets.

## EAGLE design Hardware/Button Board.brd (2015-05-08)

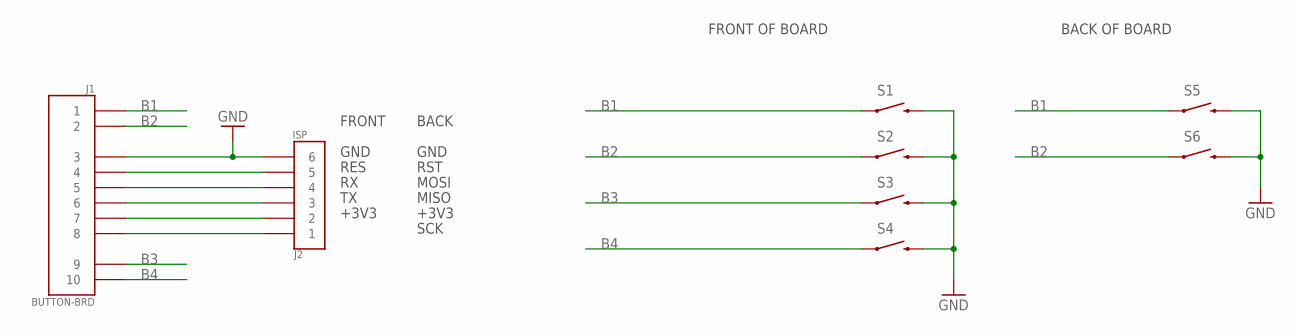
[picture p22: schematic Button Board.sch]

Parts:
J1: BUTTON-BRD
J2: ISP
S1, S2, S3, S4, S5, S6: TACT-SMD

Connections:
B1: J1.1, S1.P$1 (1), S5.P$1 (1)
B2: J1.2, S2.P$1 (1), S6.P$1 (1)
B3: J1.9, S3.P$1 (1)
B4: J1.10, S4.P$1 (1)
GND: J1.3, J2.P$6 (6), S1.P$3 (2), S2.P$3 (2), S3.P$3 (2), S4.P$3 (2), S5.P$3 (2), S6.P$3 (2)
unnamed: J1.4, J2.P$5 (5)
unnamed: J1.7, J2.P$2 (2)
unnamed: J1.5, J2.P$4 (4)
unnamed: J1.6, J2.P$3 (3)
unnamed: J1.8, J2.P$1 (1)

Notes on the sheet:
FRONT OF BOARD
BACK OF BOARD
FRONT
BACK
GND
+3V3
RES
MOSI
MISO
SCK
RST

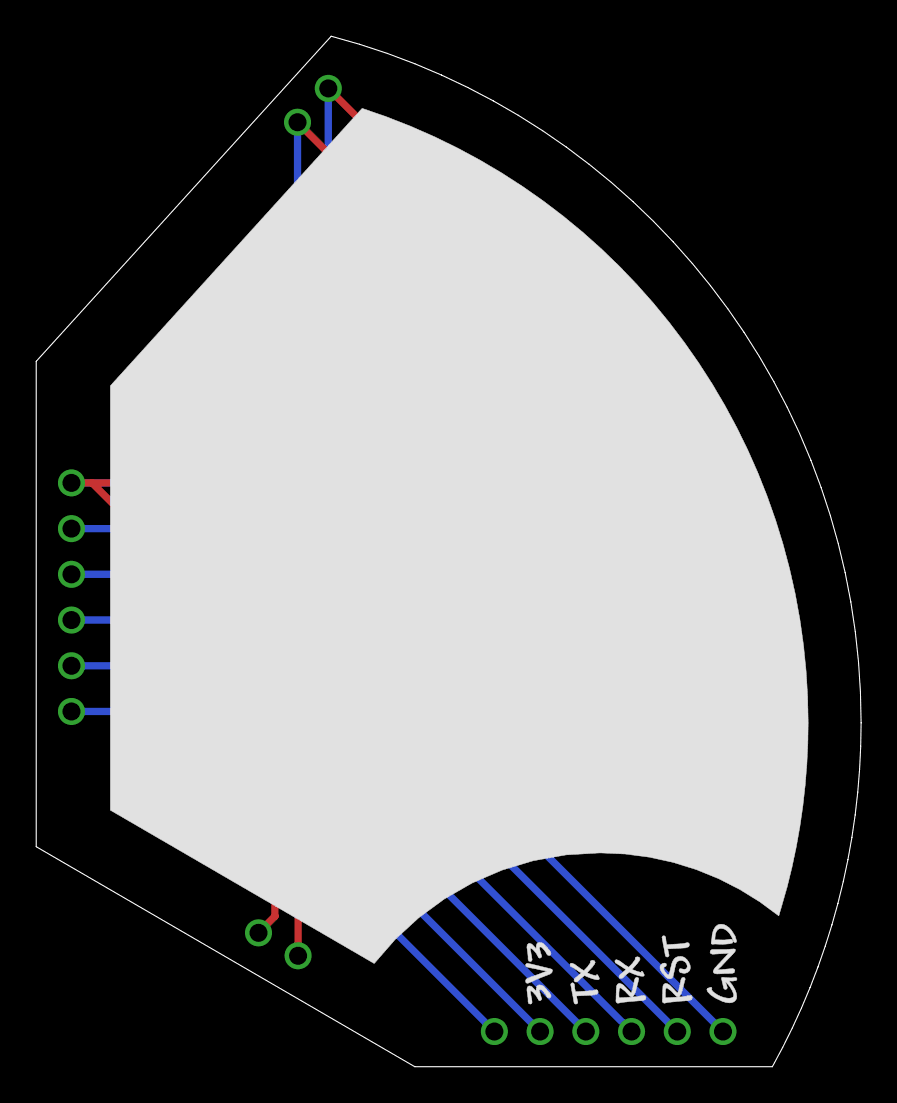
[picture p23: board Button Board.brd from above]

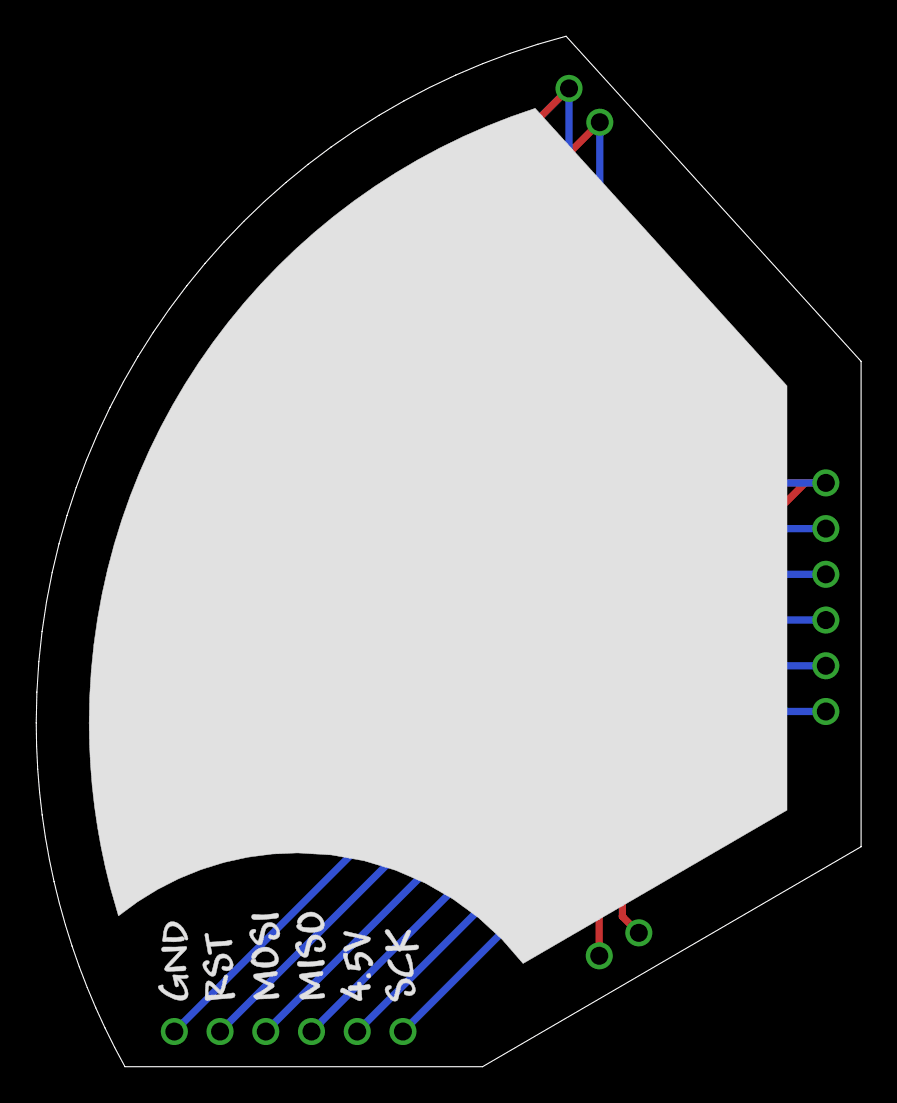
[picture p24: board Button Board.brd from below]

Board: 2 copper layers, 45.8 x 57.2 mm, 8 parts (2 on the bottom side), 10 nets.

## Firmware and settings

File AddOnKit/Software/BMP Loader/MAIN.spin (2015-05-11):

CON
  _clkmode = xtal1+pll16x
  _xinfreq = 5_000_000

  _dopin = 3   'miso
  _clkpin = 2
  _dipin = 4   'mosi
  _cspin = 5
  _cdpin = -1 ' -1 if unused.
  _wppin = -1 ' -1 if unused.
  _rtcres1 = -1 ' -1 always.
  _rtcres2 = -1 ' -1 always.
  _rtcres3 = -1 ' -1 always.

  lt = 800  'buffer /400 bytes optimo
  head = 54   'tama�o head BMP

  nRESET= 8
  RS    = 9 'D/C
  nCS   = 7
  MOSI  = 10
  SCLK  = 11
  MISO  = 12


OBJ
  fat0          : "SD-MMC_FATEngine.spin"
  disp          : "ILI9341-spi"

VAR
  byte temp1[lt],temp2[lt]
  long maxi, entry
  word lx,ly, top

pub main  | i
  disp.Start (nRESET, nCS, RS, MOSI, SCLK)

  fat0.fatEngineStart( _dopin, _clkpin, _dipin, _cspin, _wppin, _cdpin, _rtcres1, _rtcres2, _rtcres3)
  fat0.mountPartition(0)
  fat0.changeDirectory(string("img"))


  disp.SetColours ($0, $FFFF)
  disp.ClearScreen

  repeatImage

pub repeatImage | i
  fat0.listEntries("W")
  repeat while( entry := fat0.listEntries("N") )
    ifnot( fat0.listIsDirectory or fat0.listIsHidden )
      headBMP(0,true, entry)
      waitcnt (cnt + clkfreq*2)
  repeatImage

pub headBMP(x,y,puntero)|xi,yi,padd,ltr
  fat0.openFile(puntero, "R")
  fat0.readdata(@temp1,head)

  lx:=byte[@temp1][18]+byte[@temp1][19]*256
  ly:=byte[@temp1][22]+byte[@temp1][23]*256

  padd:=4-((lx*3)//4)
  if padd==4
    padd:=0

  ltr:=(lt/(lx*3+padd) *(lx*3+padd))
  ltr:=((lt-ltr)/3)*3+ltr

  yi:=y+ly-1
  xi:=x

  if x==true or y==true or x+lx>320 or yi>240
    xi:=(320-lx)/2           'centro foto
    yi:=239-(240-ly)/2       'centro foto

  disp.BMPinf(xi,yi,lx,ly)

  maxi:=(lx*ly)*3+padd*lx
  maxi/=ltr
  repeat maxi/2 +1
    fat0.readdata(@temp1,ltr)
    disp.SendBMP(@temp1,ltr)
    fat0.readdata(@temp2,ltr)
    disp.SendBMP(@temp2,ltr)
  fat0.closefile


pri drawdec(possx,possy,value,t)| i, zz

  if value < 0
    -value
    if t==0
      disp.drawcharsmall(possx,possy,"-")
      possx+=8
    else
      disp.drawchar(possx,possy,"-")
      possx+=16

  i := 1_000_000_000
  zz~

  repeat 10
    if value => i
      if t==0
        disp.drawcharsmall(possx,possy,value / i + "0")
        possx+=8
      else
        disp.drawchar(possx,possy,value / i + "0")
        possx+=16
      value //= i
      zz~~
    elseif zz or i == 1
      if t==0
        disp.drawcharsmall(possx,possy,"0")
        possx+=8
      else
        disp.drawchar(possx,possy,"0")
        possx+=16
    i /= 10

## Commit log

2015-05-08 Initial Commit
    More to come, soon. :)
    [Button Board.brd, Button Board.sch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]
2015-05-09 Button test project. Shows the state of buttons as you press them.
2015-05-09 Button test doc and info on writing your own code.
2015-05-09 Added an IO Test to test IO Pins and Buttons
2015-05-13 Fix red background color issue on all pin states when pressing 'B' button.

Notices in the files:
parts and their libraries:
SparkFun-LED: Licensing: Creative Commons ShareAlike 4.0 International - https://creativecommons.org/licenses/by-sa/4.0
